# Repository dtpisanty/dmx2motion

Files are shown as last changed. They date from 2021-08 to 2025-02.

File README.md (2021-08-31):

# dmx2motion
An ESP32 based open-hardware project to control varing frequency AC motror drivers through DMX, ArtNet, OSC and MQTT

## Circuit board files
Schematics and PCB files were created using DIP Trace

## Library dependencies
This project uses Lukas Salomons ESP32-DMX Library https://github.com/luksal/ESP32-DMX and ThingPulse's ssd1306 OLED driver https://github.com/ThingPulse/esp8266-oled-ssd1306

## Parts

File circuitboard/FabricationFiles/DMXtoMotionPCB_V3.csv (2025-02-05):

Id | Designator | Footprint | Quantity | Designation | Manufacturer and ref | Link proveedor | Diam
1 | U1 | SIP-4(7)_19.5x6x2.54 | 1 | TEA 1-0505E | Traco Power TEA 1-0505E | https://www.digikey.com.mx/en/products/detail/traco-power/TEA-1-0505E/12093309 | 0.5
2 | J4,J6,J7,J8,J9,J10 | HDR-1x2_J6 | 6 | A0 | Molex 0022232021 | https://www.digikey.com.mx/en/products/detail/molex/0022232021/26667 | 1.02
3 | R13,R5,R4,R6 | R_1206_3216Metric_Pad1.30x1.75mm_HandSolder | 4 | 470Ω | TE CRGCQ1206F470R | https://www.digikey.com.mx/en/products/detail/te-connectivity-passive-product/CRGCQ1206F470R/8576408
4 | C5 | CP_Elec_4x5.3 | 1 | 10uF | Nichicon UWZ1C100MCL1GB | https://www.digikey.com.mx/es/products/detail/nichicon/UWZ1C100MCL1GB/2550873
5 | R1,R2,R3 | R_1206_3216Metric_Pad1.30x1.75mm_HandSolder | 3 | 330Ω | Yageo RC1206JR-07330RL | https://www.digikey.com.mx/en/products/detail/yageo/RC1206JR-07330RL/729279
6 | C1,C7,C8,C9,C3,C2,C6 | C_1206_3216Metric_Pad1.33x1.80mm_HandSolder | 7 | 0.1uF | Walsin Technology Corporation 1206B104K500CT | https://www.digikey.com.mx/en/products/detail/walsin-technology-corporation/1206B104K500CT/9355102
7 | VO1,VO2,VO3 | DIP-8 | 3 | 6N137 | Everlight 6N137 | https://agelectronica.com/detalle?busca=6N%20137 | 0.56
8 | C4 | CP_Elec_4x5.3 | 1 | 4.7 | Nichicon UWP1C4R7MCL1GB | https://www.digikey.com.mx/es/products/detail/nichicon/UWP1C4R7MCL1GB/2550788
9 | J5 | HDR-1x6 | 1 | INTERFACE | Molex 0022232061 | https://www.digikey.com.mx/en/products/detail/molex/0022232061/26675?s=N4IgTCBcDaIAxzEgzGOA2AjCAugXyA | 1.02
10 | R19,R21 | R_1206_3216Metric_Pad1.30x1.75mm_HandSolder | 2 | 2KΩ | Yageo RC1206FR-072KL | https://www.digikey.com.mx/en/products/detail/yageo/RC1206FR-072KL/728612
11 | J1 | BarrelJack_Horizontal | 1 | 12V In | Same sky PJ-002AH | https://www.digikey.com.mx/en/products/detail/same-sky-formerly-cui-devices/PJ-002AH/408446
12 | U2 | DIP-8 | 1 | MAX485CPA | Maxim Integrated MAX485CPA+ | https://www.digikey.com.mx/en/products/detail/analog-devices-inc-maxim-integrated/MAX485CPA/948026 | 0.58
13 | R14,R15,R17,R16 | R_1206_3216Metric_Pad1.30x1.75mm_HandSolder | 4 | 39Ω | Yageo RC1206JR-0739RL | https://www.digikey.com.mx/en/products/detail/yageo/RC1206JR-0739RL/729289
14 | J2,J3 | HDR-1x3 | 2 | XLR3 OUT | Molex 22232031 | https://www.digikey.com.mx/en/products/detail/molex/0022232031/26669 | 1.02
15 | U5 | DIP-8 | 1 | LM358N | STM LM358N | https://agelectronica.com/detalle?busca=LM%20358N
16 | VO4 | DIP-16 | 1 | PC847 | Sharp PC847 | https://agelectronica.com/detalle?busca=PC%20847X
17 | S3,S4 | HDRF-1x3T_2.54_8x3 | 2 | MODE | E-Switch EG1218 | https://www.digikey.com.mx/en/products/detail/e-switch/EG1218/101726 | 1
18 | R8,R7 | R_1206_3216Metric_Pad1.30x1.75mm_HandSolder | 2 | 680Ω | Yageo RC1206JR-07680RL | https://www.digikey.com.mx/en/products/detail/yageo/RC1206JR-07680RL/729328
19 | R20,R10,R9,R18 | R_1206_3216Metric_Pad1.30x1.75mm_HandSolder | 4 | 1KΩ | Yageo RC1206FR-071KL | https://www.digikey.com.mx/en/products/detail/yageo/RC1206FR-071KL/728387
20 | U6 | ESP32-DevKitC | 1 | ESP32-WROOM-32U | N/A | N/A
21 | U4 | TO-220V | 1 | L78S05CV | STM L78S05CV | https://agelectronica.com/detalle?busca=L78S05CV
22 | R12 | R_1206_3216Metric_Pad1.30x1.75mm_HandSolder | 1 | 220Ω | Yageo RC1206JR-07220RL | https://www.digikey.com.mx/en/products/detail/yageo/RC1206JR-07220RL/729251
23 | D1 | LED100 | 1 | LED | Kingbright WP7113GD | https://www.digikey.com.mx/en/products/detail/kingbright/WP7113GD/1747662 | 0.9

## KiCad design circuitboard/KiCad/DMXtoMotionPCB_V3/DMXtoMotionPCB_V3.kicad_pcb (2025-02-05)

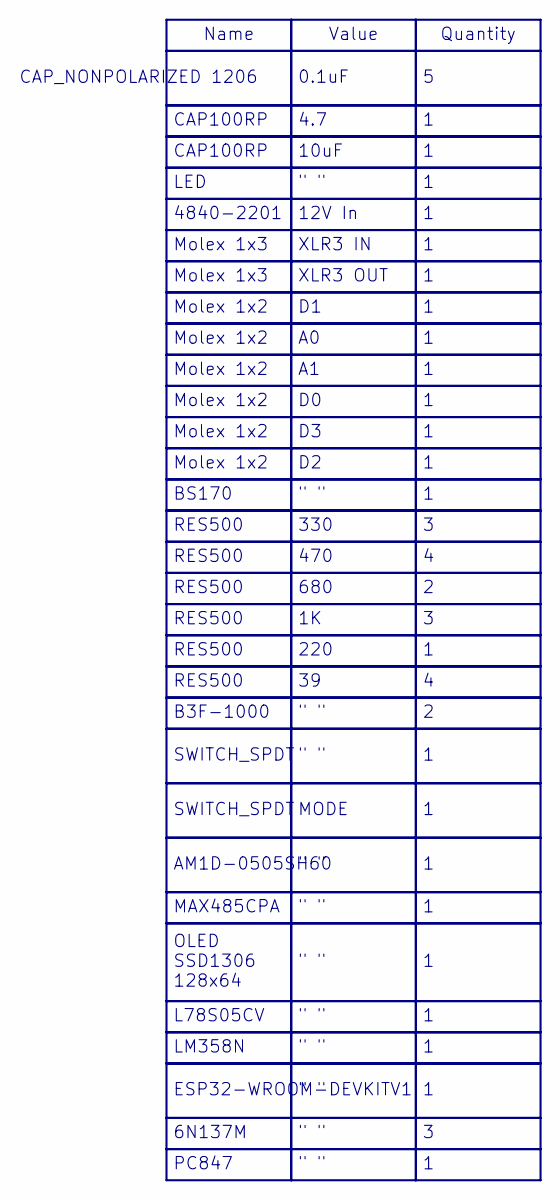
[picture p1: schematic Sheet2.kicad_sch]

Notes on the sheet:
Molex 1x2
" "
CAP100RP
470
L78S05CV
Molex 1x3
6N137M
Name
4840-2201
MAX485CPA
CAP_NONPOLARIZED 1206
RES500
4.7
Value
10uF
B3F-1000
AM1D-0505SH60
LM358N
330
PC847
680
220
0.1uF
LED
SWITCH_SPDT
XLR3 OUT
BS170
12V In
Quantity
MODE
XLR3 IN
OLED SSD1306 128x64
ESP32-WROOM-DEVKITV1

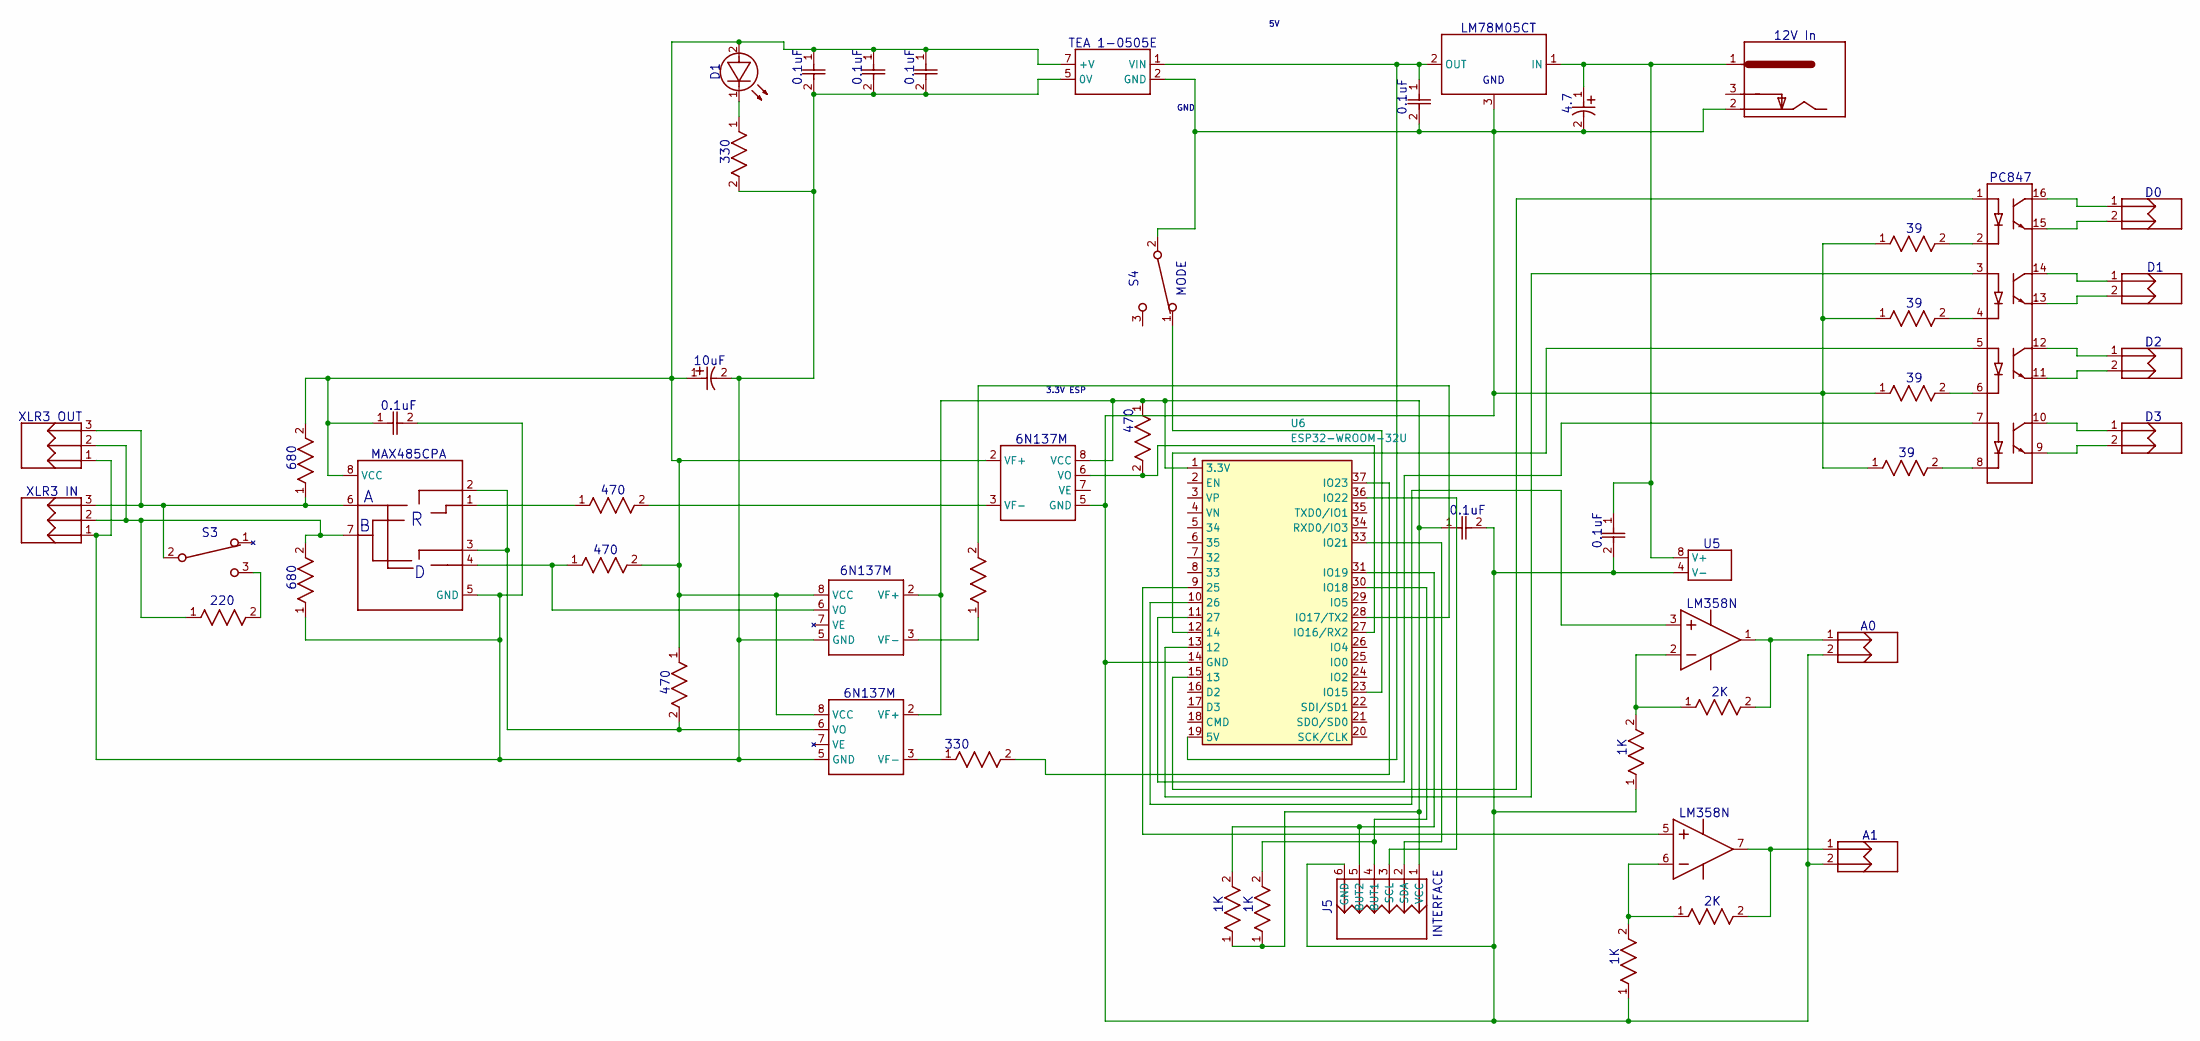
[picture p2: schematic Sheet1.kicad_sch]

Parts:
C1, C2, C3, C6, C7, C8, C9: 0.1uF; C_1206_3216Metric_Pad1.33x1.80mm_HandSolder
C4: 4.7; CP_Elec_4x5.3
C5: 10uF; CP_Elec_4x5.3
D1: LED; LED100
J1: 12V In; BarrelJack_Horizontal
J2: XLR3 IN; HDR-1X3
J3: XLR3 OUT; HDR-1X3
J4: D1; HDR-1X2
J5: INTERFACE; HDR-1X6
J6: A0; HDR-1X2
J7: A1; HDR-1X2
J8: D0; HDR-1X2
J9: D3; HDR-1X2
J10: D2; HDR-1X2
R1, R2, R3: 330; R_1206_3216Metric_Pad1.30x1.75mm_HandSolder
R4, R5, R6, R13: 470; R_1206_3216Metric_Pad1.30x1.75mm_HandSolder
R7, R8: 680; R_1206_3216Metric_Pad1.30x1.75mm_HandSolder
R9, R10, R18, R20: 1K; R_1206_3216Metric_Pad1.30x1.75mm_HandSolder
R12: 220; R_1206_3216Metric_Pad1.30x1.75mm_HandSolder
R14, R15, R16, R17: 39; R_1206_3216Metric_Pad1.30x1.75mm_HandSolder
R19, R21: 2K; R_1206_3216Metric_Pad1.30x1.75mm_HandSolder
S3: SWITCH_SPDT; HDRF-1X3T_2.54_8X3
S4: MODE; HDRF-1X3T_2.54_8X3
U1: AM1D-0505SH60; SIP-4(7)_19.5X6X2.54
U2: MAX485CPA; DIP-8
U4: LM78M05CT; TO-220V
U5: LM358N; DIP-8
U6: ESP32-WROOM-32U; ESP32-DevKitC
VO1, VO2, VO3: 6N137M; DIP-8
VO4: PC847; DIP-16

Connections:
3.3V_ESP: C7.1, J5.1 (VCC), R9.1 (A), R10.1 (A), R13.1 (A), U6.1 (3.3V), VO1.8 (VCC), VO2.2 (VF+), VO3.2 (VF+)
5V: C9.1, U1.1 (VIN), U4.2 (OUT), U6.19 (5V)
12V: C4.1 (PLUS), C6.1, J1.1, U4.1 (IN), U5.8 (V+)
But1: J5.4 (BUT1), R10.2 (B), U6.30 (IO18)
But2: J5.5 (BUT2), R9.2 (B), U6.31 (IO19)
GND: C4.2 (MINUS), C6.2, C7.2, C9.2, J1.2, J5.6 (GND), J6.2, J7.2, R14.1 (A), R15.1 (A), R16.1 (A), R17.1 (A), R18.1 (A), R20.1 (A), S4.2 (C1), U1.2 (GND), U4.3 (GND), U5.4 (V-), U6.14 (GND), U6.32 (GND), U6.38 (GND), VO1.5 (GND)
ISO-5V: C1.1, C2.1, C3.1, C5.1 (PLUS), C8.1, D1.2 (A), R5.2 (B), R6.1 (A), R7.2 (B), U1.7 (+V), U2.8 (VCC), VO1.2 (VF+), VO2.8 (VCC), VO3.8 (VCC)
ISO-GND: C1.2, C2.2, C3.2, C5.2 (MINUS), C8.2, J2.1, J3.1, R1.2 (B), R8.1 (A), U1.5 (0V), U2.5 (GND), VO2.5 (GND), VO3.5 (GND)
Net_0: R17.2 (B), VO4.2 (Cathode@1)
Net_1: U6.12 (14), VO4.5 (Anode@3)
Net_2: U6.11 (27), VO4.7 (Anode@4)
Net_4: D1.1 (K), R1.1 (A)
Net_6: U6.15 (13), VO4.1 (Anode@1)
Net_7: U6.13 (12), VO4.3 (Anode@2)
Net_8: U5.5 (IN+), U6.9 (25)
Net_9: R2.1 (A), VO2.3 (VF-)
Net_10: R3.2 (B), U6.37 (IO23)
Net_11: R3.1 (A), VO3.3 (VF-)
Net_12: R4.2 (B), VO1.3 (VF-)
Net_13: R4.1 (A), U2.1 (RO)
Net_14: R6.2 (B), U2.2 (~RE), U2.3 (DE), VO3.6 (VO)
Net_15: R5.1 (A), U2.4 (DI), VO2.6 (VO)
Net_16: J2.2, J3.2, R8.2 (B), R12.1 (A), U2.7 (B)
Net_17: J2.3, J3.3, R7.1 (A), S3.2 (C1), U2.6 (A)
Net_18: J7.1, R19.2 (B), U5.7 (OUT)
Net_21: R18.2 (B), R19.1 (A), U5.6 (IN-)
Net_22: S4.1 (C2), U6.23 (IO15)
Net_24: U5.3 (IN+), U6.10 (26)
Net_32: J5.2 (SDA), U6.33 (IO21)
Net_33: J5.3 (SCL), U6.36 (IO22)
Net_34: R12.2 (B), S3.3 (C3)
Net_35: R14.2 (B), VO4.4 (Cathode@2)
Net_36: R15.2 (B), VO4.6 (Cathode@3)
Net_37: R16.2 (B), VO4.8 (Cathode@4)
Net_38: J8.2, VO4.15 (Emitter@1)
Net_39: J8.1, VO4.16 (Collector@1)
Net_40: J4.1, VO4.14 (Collector@2)
Net_41: J4.2, VO4.13 (Emitter@2)
Net_42: J10.1, VO4.12 (Collector@3)
Net_43: J10.2, VO4.11 (Emitter@3)
Net_44: J9.1, VO4.10 (Collector@4)
Net_45: J9.2, VO4.9 (Emitter@4)
Net_46: J6.1, R21.2 (B), U5.1 (OUT)
Net_47: R20.2 (B), R21.1 (A), U5.2 (IN-)
RX: R13.2 (B), U6.27 (IO16/RX2), VO1.6 (VO)
TX: R2.2 (B), U6.28 (IO17/TX2)

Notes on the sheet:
PC847
330
6N137M
GND
0.1uF
10uF
470
XLR3 IN
XLR3 OUT
LM358N
MODE
TEA 1-0505E
680
INTERFACE
3.3V ESP
12V In
220
LM78M05CT
MAX485CPA
4.7

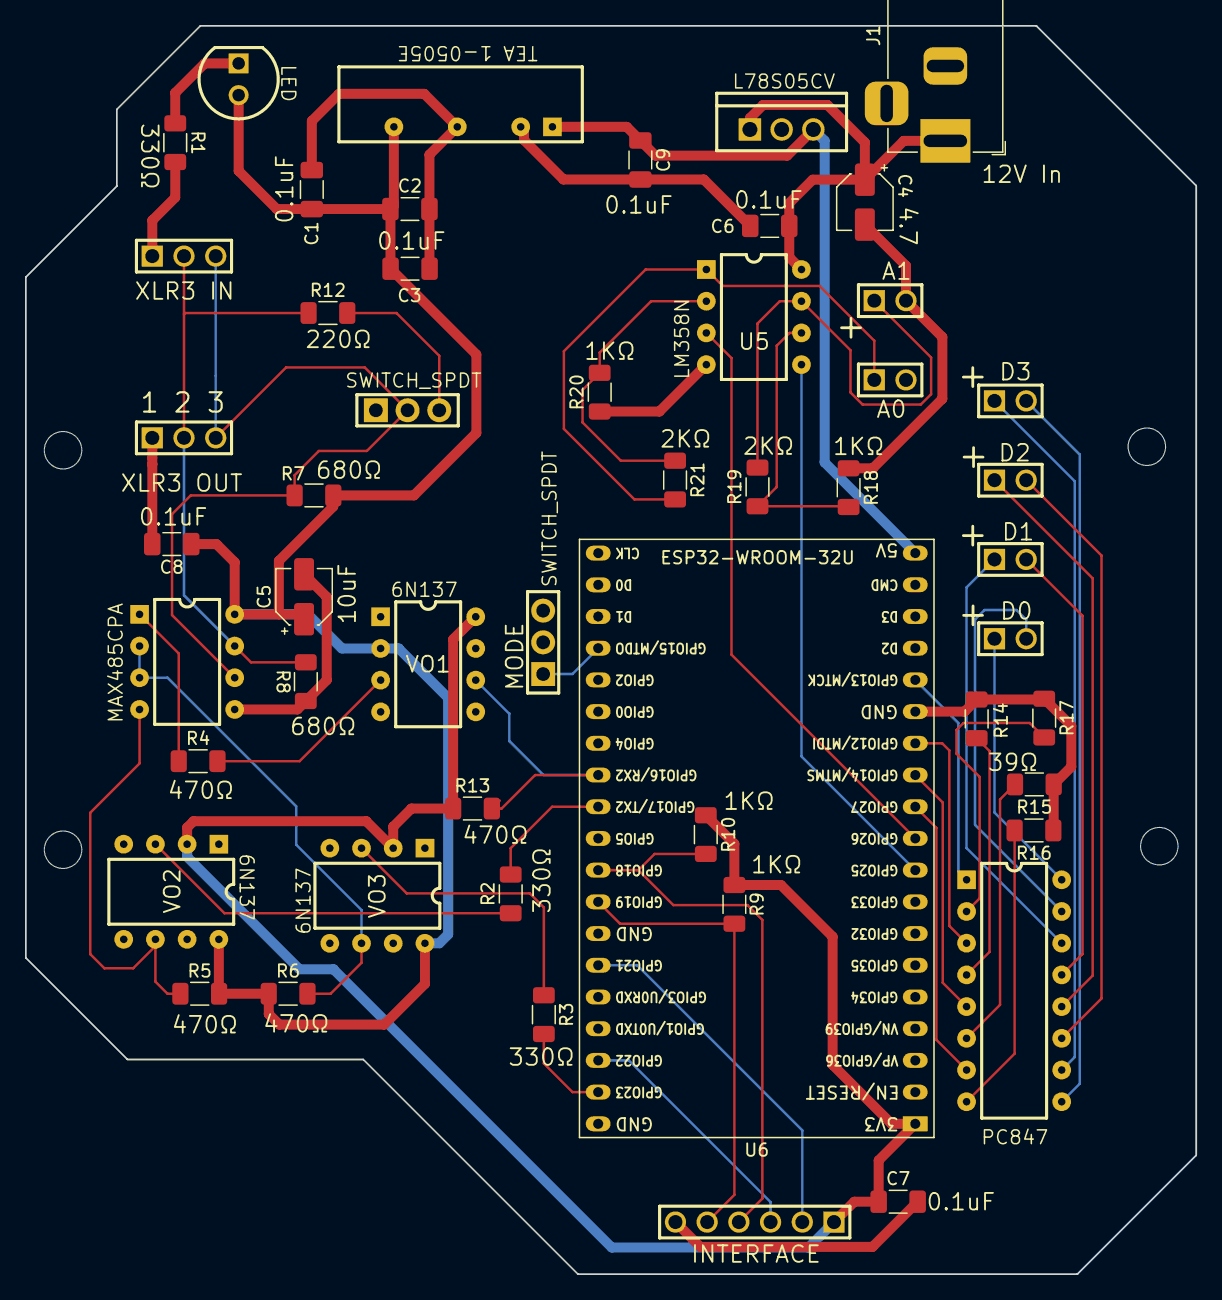
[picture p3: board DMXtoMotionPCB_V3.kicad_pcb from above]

Board: 2 copper layers, 93.8 x 100.0 mm, 55 parts (0 on the bottom side), 46 nets.

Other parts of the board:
@HOLE0, @HOLE1, @HOLE2, @HOLE3: (no value)

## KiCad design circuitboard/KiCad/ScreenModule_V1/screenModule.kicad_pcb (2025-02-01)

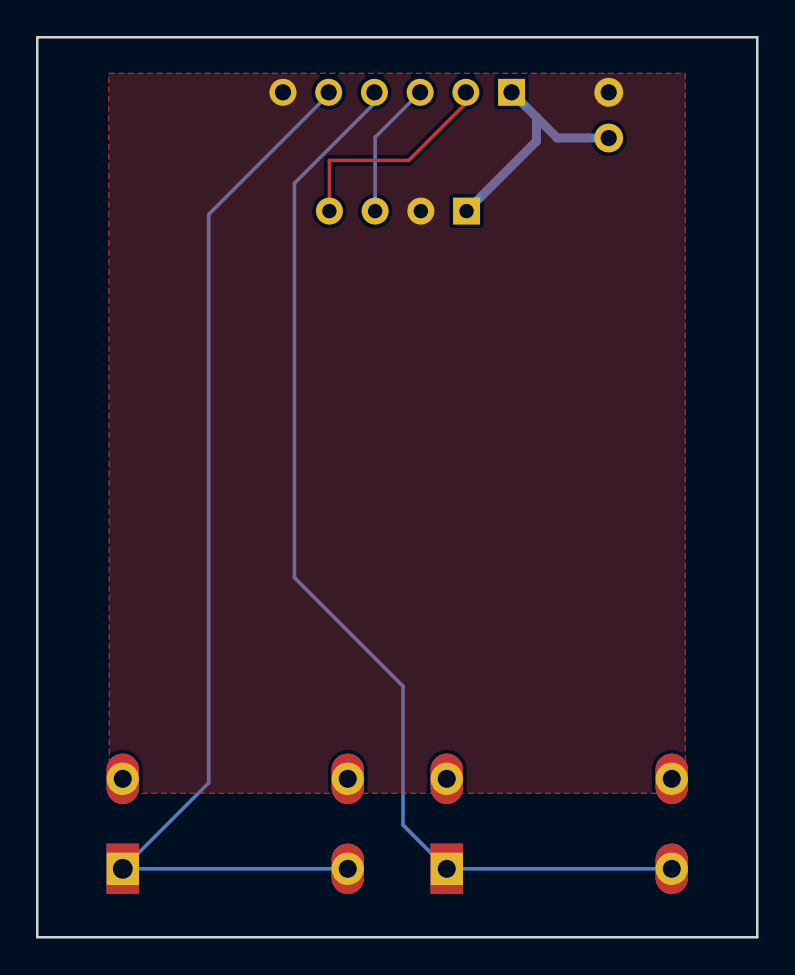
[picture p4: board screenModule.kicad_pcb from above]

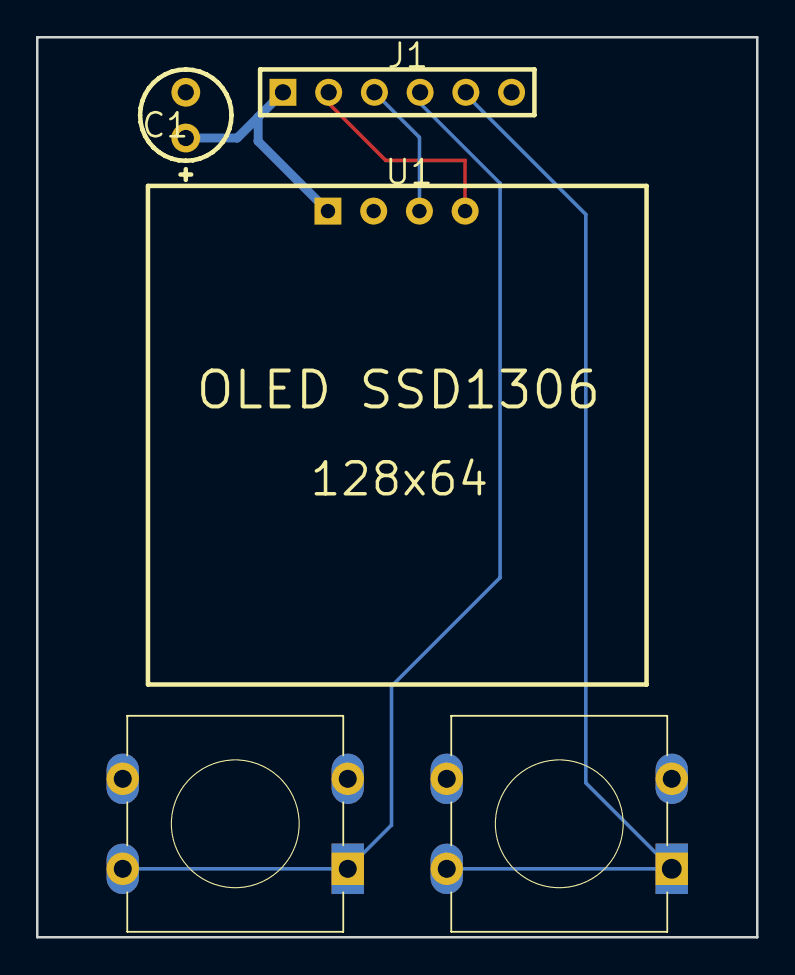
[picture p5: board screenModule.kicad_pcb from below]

Board: 2 copper layers, 40.0 x 50.0 mm, 11 parts (11 on the bottom side), 6 nets.

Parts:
C1: 4.7uF; CAPPR-2.54_5.08
J1: HDR-1X6; HDR-1x6
PAD1: PAD; PAD_PAD1
PAD2, PAD3, PAD4, PAD6, PAD7, PAD8: PAD; PAD_PAD2
PAD5: PAD
U1: OLED SSD1306 128X64; OLED_SSD1306

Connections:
Net_0: C1.2, J1.6, U1.2
Net_1: C1.1, J1.1, U1.1
Net_2: J1.2, U1.4
Net_3: J1.3, U1.3
Net_5: J1.5, PAD1.1, PAD2.2
Net_6: J1.4, PAD5.1, PAD6.2

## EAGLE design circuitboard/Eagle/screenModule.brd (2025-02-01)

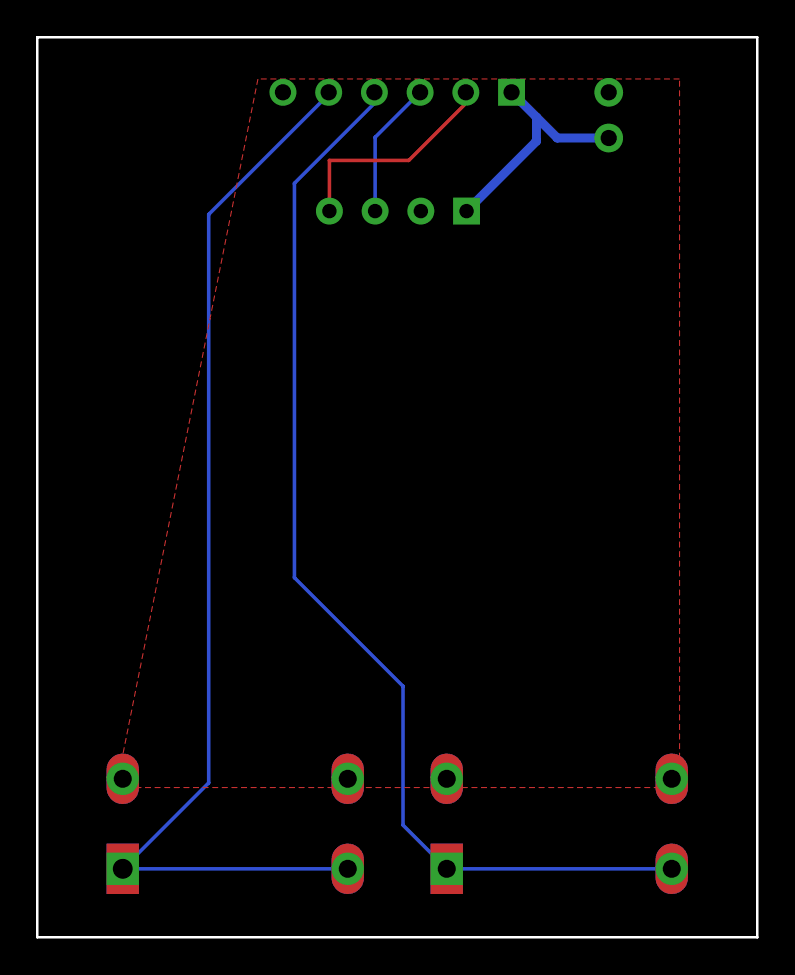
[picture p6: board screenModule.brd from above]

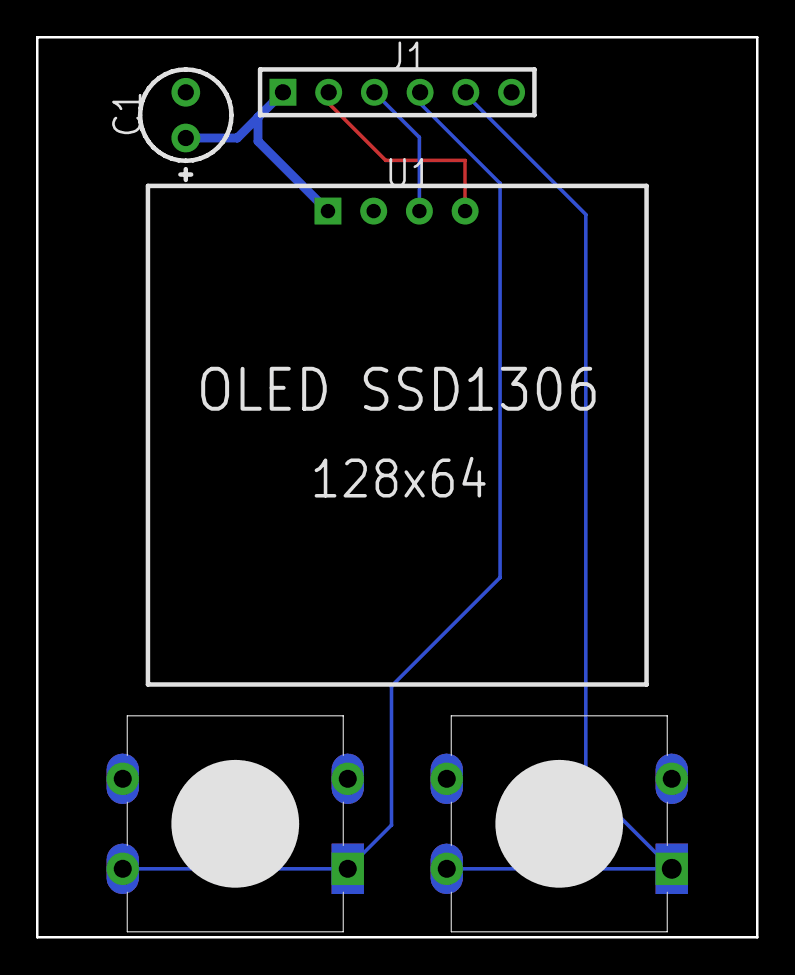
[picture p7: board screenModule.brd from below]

Board: 2 copper layers, 40.0 x 50.0 mm, 11 parts (11 on the bottom side), 6 nets.

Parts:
C1: 4.7uF; CAPPR-2.54/5.08
J1: HDR-1X6; HDR-1x6
PAD1: PAD; PAD_PAD1
PAD2, PAD3, PAD4, PAD6, PAD7, PAD8: PAD; PAD_PAD2
PAD5: PAD
U1: OLED SSD1306 128X64; OLED_SSD1306

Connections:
Net_0: C1.2, J1.6, PAD3.3, PAD4.4, PAD7.3, PAD8.4, U1.2
Net_1: C1.1, J1.1, U1.1
Net_2: J1.2, U1.4
Net_3: J1.3, U1.3
Net_5: J1.5, PAD1.1, PAD2.2
Net_6: J1.4, PAD5.1, PAD6.2

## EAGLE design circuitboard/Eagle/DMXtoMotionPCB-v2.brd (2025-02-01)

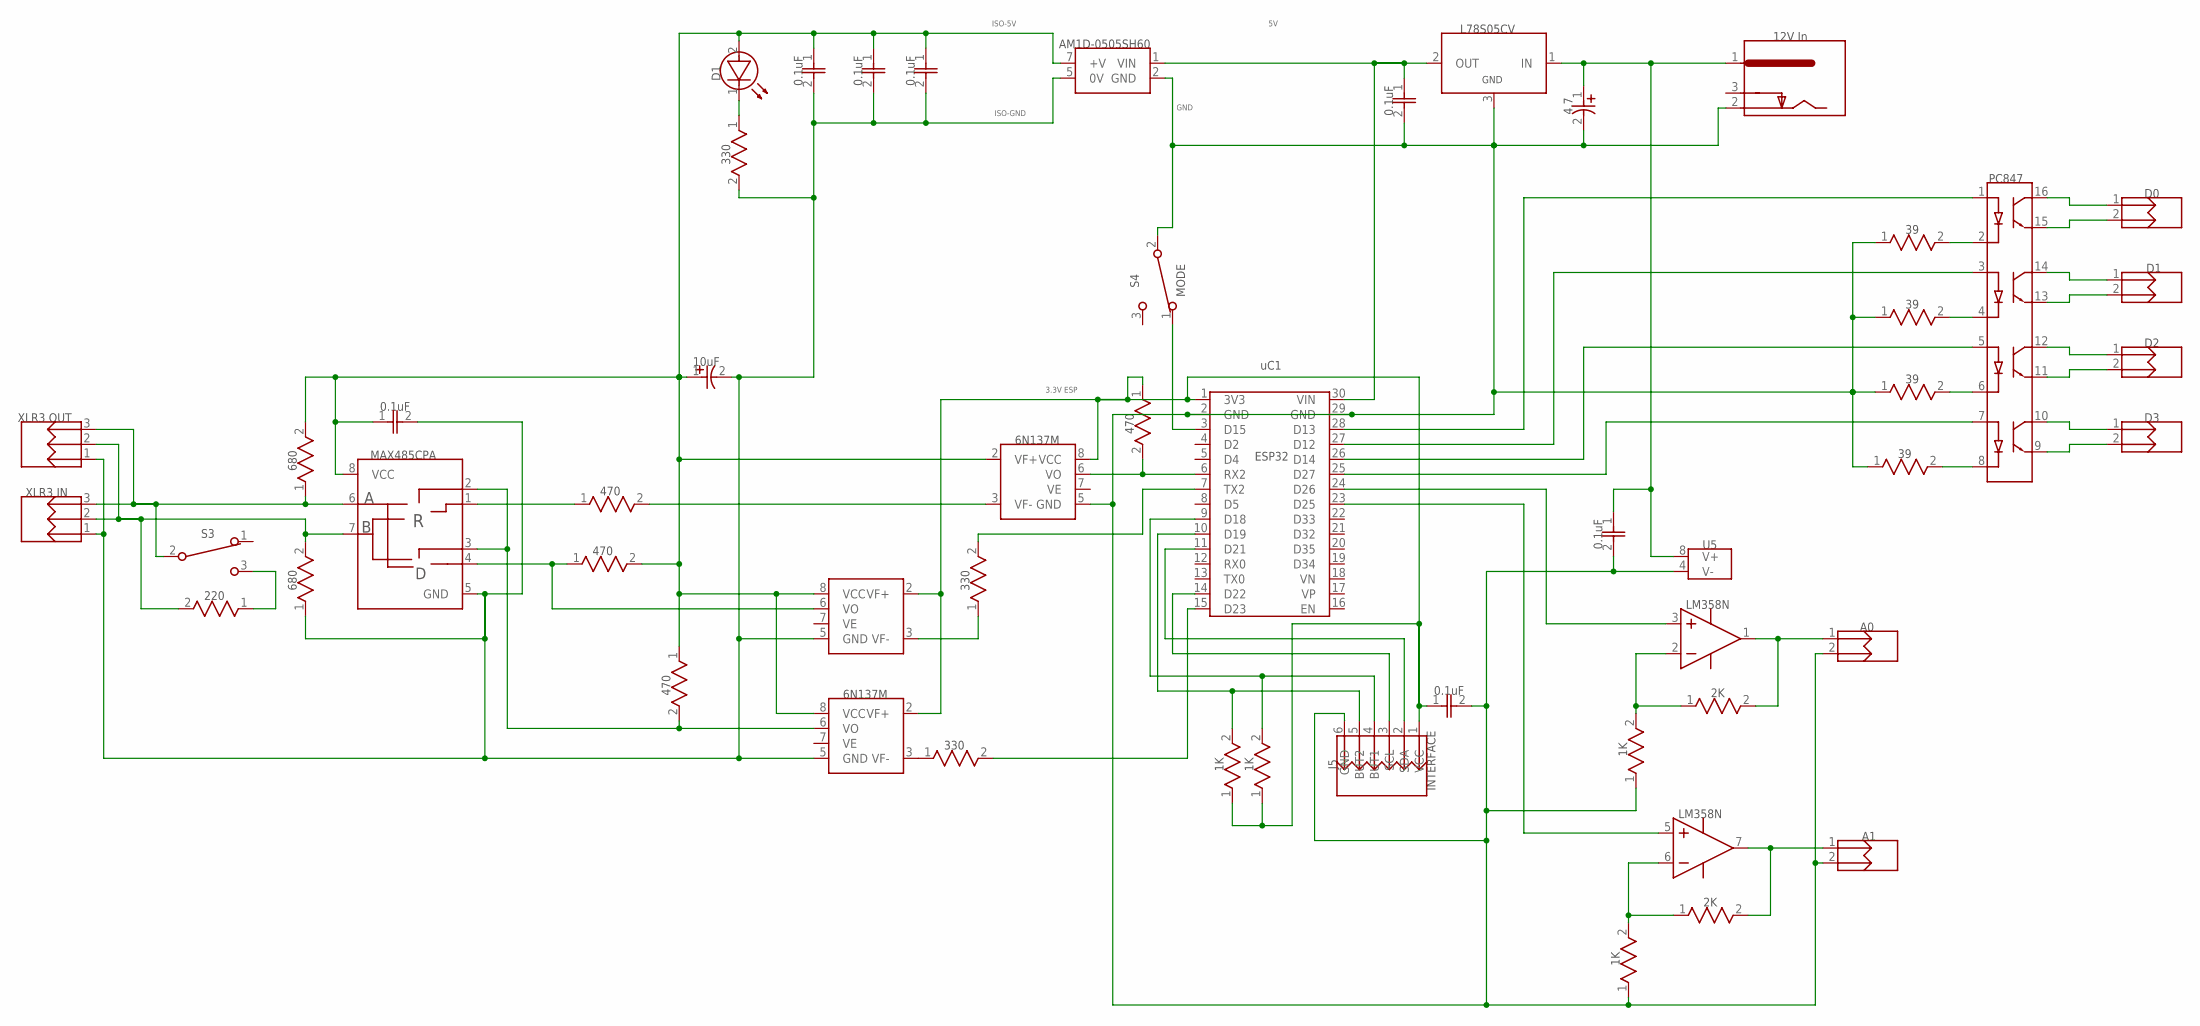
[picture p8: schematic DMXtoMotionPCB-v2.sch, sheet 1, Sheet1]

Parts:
C1, C2, C3, C6, C7, C8, C9: 0.1uF; CAP-5.08/9.15X3
C4: 4.7; CAPPR-2.54/5.08
C5: 10uF; CAPPR-2.54/5.08
D1: LED; LED100
J1: 12V In; 4840-2211
J2: XLR3 IN; HDR-1X3
J3: XLR3 OUT; HDR-1X3
J4: D1; HDR-1X2
J5: INTERFACE; HDR-1X6
J6: A0; HDR-1X2
J7: A1; HDR-1X2
J8: D0; HDR-1X2
J9: D3; HDR-1X2
J10: D2; HDR-1X2
R1, R2, R3: 330; RES-12.7/7.6X2.5
R4, R5, R6, R13: 470; RES-12.7/7.6X2.5
R7, R8: 680; RES-12.7/7.6X2.5
R9, R10, R18, R20: 1K; RES-12.7/7.6X2.5
R12: 220; RES-12.7/7.6X2.5
R14, R15, R16, R17: 39; RES-12.7/7.6X2.5
R19, R21: 2K; RES-12.7/7.6X2.5
S3: SWITCH_SPDT; HDRF-1X3T/2.54/8X3
S4: MODE; HDRF-1X3T/2.54/8X3
U1: AM1D-0505SH60; SIP-4(7)/19.5X6X2.54
U2: MAX485CPA; DIP-8
U4: L78S05CV; TO-220V
U5: LM358N; DIP-8
VO1: 6N137M; DIP-8
VO2, VO3: 6N137M_10; DIP-8
VO4: PC847; DIP-16
uC1: ESP32-WROOM-DEVKITV1; ESP32-DEVKITV1

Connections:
3.3V_ESP: C7.1, J5.1 (VCC), R9.1 (A), R10.1 (A), R13.1 (A), VO1.8 (VCC), VO2.2 (VF+), VO3.2 (VF+), uC1.1 (3V3)
5V: C9.1, U1.1 (VIN), U4.2 (OUT), uC1.30 (VIN)
12V: C4.1 (PLUS), C6.1, J1.1, U4.1 (IN), U5.8 (V+)
But1: J5.4 (BUT1), R10.2 (B), uC1.9 (D18)
But2: J5.5 (BUT2), R9.2 (B), uC1.10 (D19)
GND: C4.2 (MINUS), C6.2, C7.2, C9.2, J1.2, J5.6 (GND), J6.2, J7.2, R14.1 (A), R15.1 (A), R16.1 (A), R17.1 (A), R18.1 (A), R20.1 (A), S4.2 (C1), U1.2 (GND), U4.3 (GND), U5.4 (V-), VO1.5 (GND), uC1.2 (GND), uC1.29 (GND)
ISO-5V: C1.1, C2.1, C3.1, C5.1 (PLUS), C8.1, D1.2 (A), R5.2 (B), R6.1 (A), R7.2 (B), U1.7 (+V), U2.8 (VCC), VO1.2 (VF+), VO2.8 (VCC), VO3.8 (VCC)
ISO-GND: C1.2, C2.2, C3.2, C5.2 (MINUS), C8.2, J2.1, J3.1, R1.2 (B), R8.1 (A), U1.5 (0V), U2.5 (GND), VO2.5 (GND), VO3.5 (GND)
Net_0: R17.2 (B), VO4.2 (Cathode)
Net_1: VO4.5 (Anode), uC1.26 (D14)
Net_2: VO4.7 (Anode), uC1.25 (D27)
Net_4: D1.1 (K), R1.1 (A)
Net_6: VO4.1 (Anode), uC1.28 (D13)
Net_7: VO4.3 (Anode), uC1.27 (D12)
Net_8: U5.5 (IN+), uC1.23 (D25)
Net_9: R2.1 (A), VO2.3 (VF-)
Net_10: R3.2 (B), uC1.15 (D23)
Net_11: R3.1 (A), VO3.3 (VF-)
Net_12: R4.2 (B), VO1.3 (VF-)
Net_13: R4.1 (A), U2.1 (RO)
Net_14: R6.2 (B), U2.2 (!RE), U2.3 (DE), VO3.6 (VO)
Net_15: R5.1 (A), U2.4 (DI), VO2.6 (VO)
Net_16: J2.2, J3.2, R8.2 (B), R12.2 (B), U2.7 (B)
Net_17: J2.3, J3.3, R7.1 (A), S3.2 (C1), U2.6 (A)
Net_18: J7.1, R19.2 (B), U5.7 (OUT)
Net_21: R18.2 (B), R19.1 (A), U5.6 (IN-)
Net_22: S4.1 (C2), uC1.3 (D15)
Net_24: U5.3 (IN+), uC1.24 (D26)
Net_32: J5.2 (SDA), uC1.11 (D21)
Net_33: J5.3 (SCL), uC1.14 (D22)
Net_34: R12.1 (A), S3.3 (C3)
Net_35: R14.2 (B), VO4.4 (Cathode)
Net_36: R15.2 (B), VO4.6 (Cathode)
Net_37: R16.2 (B), VO4.8 (Cathode)
Net_38: J8.2, VO4.15 (Emitter)
Net_39: J8.1, VO4.16 (Collector)
Net_40: J4.1, VO4.14 (Collector)
Net_41: J4.2, VO4.13 (Emitter)
Net_42: J10.1, VO4.12 (Collector)
Net_43: J10.2, VO4.11 (Emitter)
Net_44: J9.1, VO4.10 (Collector)
Net_45: J9.2, VO4.9 (Emitter)
Net_46: J6.1, R21.2 (B), U5.1 (OUT)
Net_47: R20.2 (B), R21.1 (A), U5.2 (IN-)
RX: R13.2 (B), VO1.6 (VO), uC1.6 (RX2)
TX: R2.2 (B), uC1.7 (TX2)

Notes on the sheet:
0.1uF
4.7
10uF
12V In
XLR3 IN
XLR3 OUT
INTERFACE
330
470
680
220
MODE
AM1D-0505SH60
MAX485CPA
GND
L78S05CV
LM358N
ESP32
uC1
6N137M
PC847
3.3V ESP
ISO-5V
ISO-GND

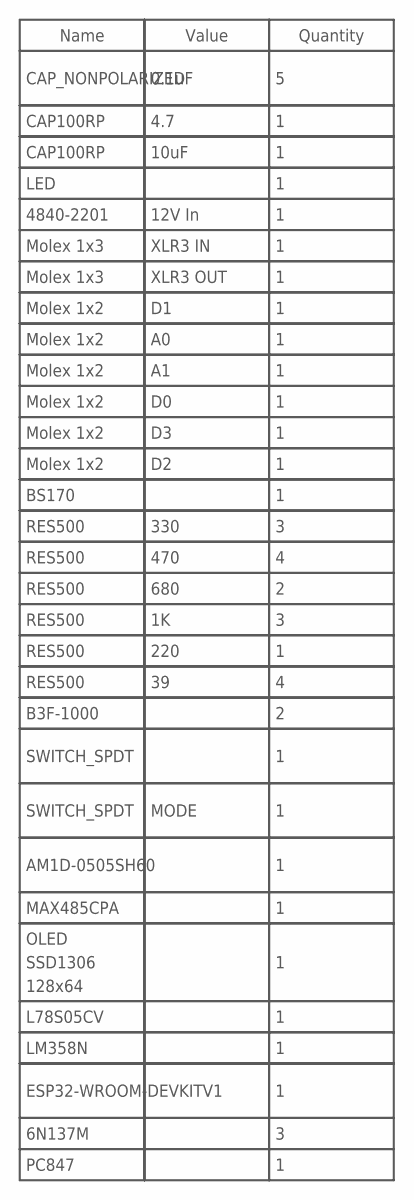
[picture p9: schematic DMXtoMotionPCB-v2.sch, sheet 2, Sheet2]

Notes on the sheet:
Name
CAP_NONPOLARIZED
CAP100RP
LED
4840-2201
Molex 1x3
Molex 1x2
BS170
RES500
B3F-1000
SWITCH_SPDT
AM1D-0505SH60
MAX485CPA
OLED SSD1306 128x64
L78S05CV
LM358N
ESP32-WROOM-DEVKITV1
6N137M
PC847
Value
0.1uF
4.7
10uF
12V In
XLR3 IN
XLR3 OUT
330
470
680
220
MODE
Quantity

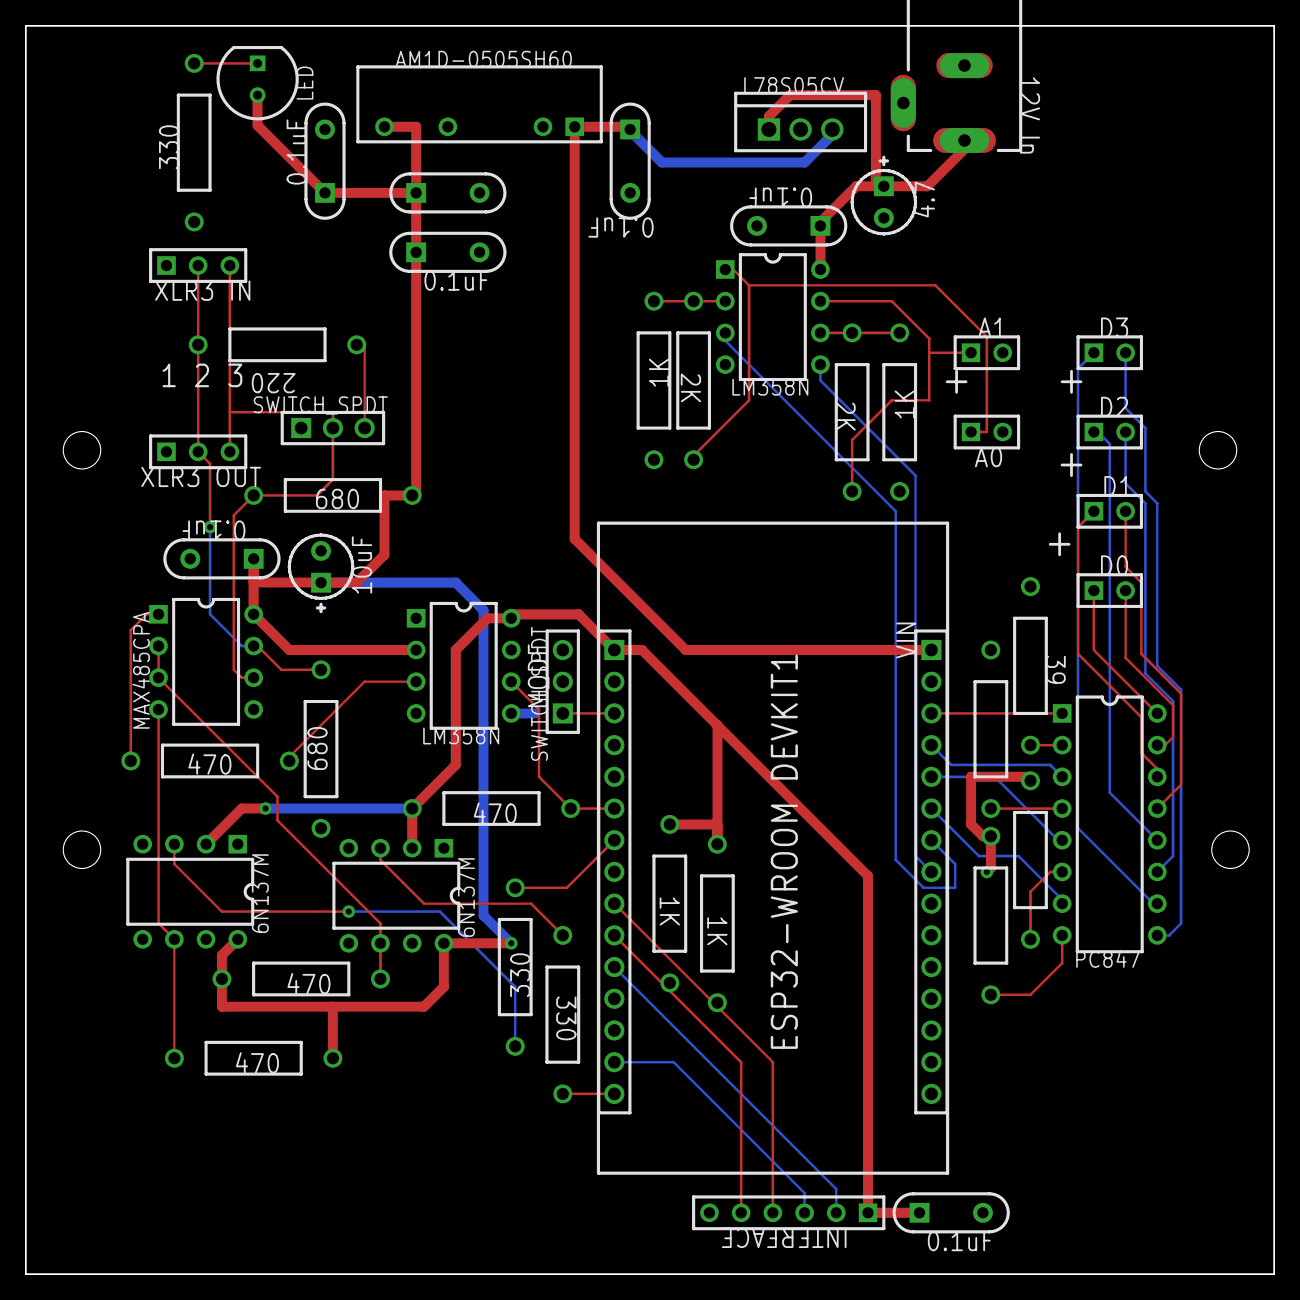
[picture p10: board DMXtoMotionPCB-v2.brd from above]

Board: 2 copper layers, 100.0 x 100.0 mm, 51 parts (0 on the bottom side), 46 nets.

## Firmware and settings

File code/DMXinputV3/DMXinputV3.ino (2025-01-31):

#include <dmx.h>
#include "SSD1306Wire.h"
#include <EEPROM.h>
#include "WiFi.h"
#include <PubSubClient.h>

#define debug true

//EEPROM
#define EEPROM_SIZE 1
bool saveChannel = false;


//////////////////////////////////////////////////////
//         PINES SALIDA (13,12,14,27,26,25)         //
//////////////////////////////////////////////////////
#define enablePin 23
#define dOut0 13
#define dOut1 12
#define dOut2 14
#define dOut3 27
#define DAC0 26
#define DAC1 25

//////////////////////////////////////////////////////
//                BOTONES                           //
//////////////////////////////////////////////////////
#define chUp 18
#define chDown 19
bool showChannel = false;
long chShowTimer = 0;

//MODO
#define modeSwitch 15
int modo; // 0/LOW=DMX  1/HIGH=MQTT

//////////////////////////////////////////////////////
//                PANTALLA                          //
//////////////////////////////////////////////////////
SSD1306Wire display(0x3c, SDA, SCL);
long lastShow = 0;
bool render = true;

//////////////////////////////////////////////////////
//                VARIABLES                         //
//////////////////////////////////////////////////////
bool eStop = false;
int readcycle = 0;
int valD0 = 0;
int valD1 = 0;
int valA0 = 0;
int valD2 = 0;
int valD3 = 0;
int valA1 = 0;

int startDMXChannel = 0;
long lastAdd = 0;

//////////////////////////////////////////////////////
//                 INTERRUPTS                       //
//////////////////////////////////////////////////////
void IRAM_ATTR addChannel() {
  saveChannel = true;
  //Debounce
  if (millis() - lastAdd < 150) {
    return;
  }
  lastAdd = millis();
  startDMXChannel++;
  if (startDMXChannel > 510) {
    startDMXChannel = 510;
  }
  showChannel = true;
  chShowTimer = millis();
  if (EEPROM.read(0) == startDMXChannel) {
    saveChannel = false;
  }
#if debug
  Serial.println(startDMXChannel);
#endif
}

long lastSubtract = 0;
void IRAM_ATTR subtractChannel() {
  saveChannel = true;
  if (millis() - lastSubtract < 150) {
    return;
  }
  lastSubtract = millis();
  startDMXChannel--;
  if (startDMXChannel < 1) {
    startDMXChannel = 1;
  }
  showChannel = true;
  chShowTimer = millis();
  if (EEPROM.read(0) == startDMXChannel) {
    saveChannel = false;
  }

#if debug
  Serial.println(startDMXChannel);
#endif
}
void IRAM_ATTR reboot() {
  ESP.restart();
}
//////////////////////////////////////////////////////
//                 WIFI                             //
//////////////////////////////////////////////////////
//const char* ssid = "Totalplay-7F9A";
//const char* password = "7F9AE96AmFef7T6b";
const char* ssid = "IZZI-4B88";
const char* password = "usy7qijh";
void setup_wifi() {
  delay(5);
#if debug
  Serial.println();
  Serial.print("Conectando a ");
  Serial.println(ssid);
#endif
  WiFi.mode(WIFI_STA);
  WiFi.begin(ssid, password);

  while (WiFi.status() != WL_CONNECTED) {
    display.clear();
    display.setTextAlignment(TEXT_ALIGN_CENTER);
    display.setFont(ArialMT_Plain_16);
    display.drawString(64, 10, "CONECTANDO");
    display.drawString(64, 30, ssid);
    display.display();
    delay(500);
#if debug
    Serial.print(".");
#endif
  }
#if debug
  Serial.println("");
  Serial.println("WiFi conectado");
  Serial.println("IP local: ");
  Serial.println(WiFi.localIP());
#endif
}

//////////////////////////////////////////////////////
//                 MQTT                             //
//////////////////////////////////////////////////////
const char* mqtt_server = "tarimas.local";
const int port = 1883;
WiFiClient espClient;
PubSubClient cliente(espClient);
const int statLed = 2;

void reconnect() {
  // Loop until we're reconnected
  while (!cliente.connected()) {
#if debug
    Serial.print("Attempting MQTT connection...");
#endif
    // Create a random client ID
    String clientId = "totaShow-Tarima1";
    // Attempt to connect
    //String id, String willTopic, uint8_t willQos, bool willRetain, String willMessage
    if (cliente.connect(clientId.c_str(), "totalShow", "showtotal2024","tarima1/estado", 2, true, "0")) {
#if debug
      Serial.println("MQTT conectado");
#endif
      // Once connected, publish an announcement...
      cliente.publish("tarima1/estado", "1");
    } else {
#if debug
      Serial.print("Error, codigo=");
      Serial.print(cliente.state());
      Serial.println("intentando en 3 seg");
#endif
      // Wait 5 seconds before retrying
      delay(3000);
    }
  }
  char chTopic[9];
  sprintf(chTopic, "canal/%d", startDMXChannel);
  cliente.subscribe(chTopic);
  sprintf(chTopic, "canal/%d", startDMXChannel + 1);
  cliente.subscribe(chTopic);
  sprintf(chTopic, "canal/%d", startDMXChannel + 2);
  cliente.subscribe(chTopic);
  sprintf(chTopic, "canal/%d", startDMXChannel + 3);
  cliente.subscribe(chTopic);
  sprintf(chTopic, "canal/%d", startDMXChannel + 4);
  cliente.subscribe(chTopic);
  sprintf(chTopic, "canal/%d", startDMXChannel + 5);
  cliente.subscribe(chTopic);
  digitalWrite(statLed, HIGH);
#if debug
  Serial.println("");
  Serial.println("Subscrito a canal/" + String(startDMXChannel));
  Serial.println("Subscrito a canal/" + String(startDMXChannel + 1));
  Serial.println("Subscrito a canal/" + String(startDMXChannel + 2));
  Serial.println("Subscrito a canal/" + String(startDMXChannel + 3));
  Serial.println("Subscrito a canal/" + String(startDMXChannel + 4));
  Serial.println("Subscrito a canal/" + String(startDMXChannel + 5));
#endif

}
void callback(char* topic, byte * payload, unsigned int length) {
#if debug
  Serial.print("Mensaje llego a: ");
  Serial.println(topic);
  Serial.print("Len: ");
  Serial.println(length);
#endif
  String strTopic = String(topic);
  char entrada[length];
  for (int i = 0; i < length; i++) {
    entrada[i] = payload[i];
  }
  //Serial.println(entrada);
  int entradaInt;
  entradaInt = String(entrada).substring(0, length).toInt(); //Convertir entrada de char[] a int
#if debug
  Serial.println(entradaInt);
#endif

  if (strTopic.indexOf(String(startDMXChannel)) > 0) {
    valD0 = entradaInt;
#if debug
    Serial.print("D0=");
    Serial.println(entradaInt);
#endif
  }
  else if (strTopic.indexOf(String(startDMXChannel + 1)) > 0) {
    valD1 = entradaInt;
    Serial.print("D1=");
    Serial.println(entradaInt);
  }
  else if (strTopic.indexOf(String(startDMXChannel + 2)) > 0) {
    valA0 = entradaInt;
    Serial.print("A0=");
    Serial.println(entradaInt);
  }
  else if (strTopic.indexOf(String(startDMXChannel + 3)) > 0) {
    valD2 = entradaInt;
    Serial.print("D2=");
    Serial.println(entradaInt);
  }
  else if (strTopic.indexOf(String(startDMXChannel + 4)) > 0) {
    valD3 = entradaInt;
    Serial.print("D3=");
    Serial.println(entradaInt);
  }
  else if (strTopic.indexOf(String(startDMXChannel + 5)) > 0) {
    valA1 = entradaInt;
    Serial.print("A1=");
    Serial.println(entradaInt);
  }
}

//////////////////////////////////////////////////////
//                 SETUP                            //
//////////////////////////////////////////////////////
void setup() {
#if debug
  Serial.begin(115200);
#endif

  //ENTRADAS
  pinMode(chUp, INPUT_PULLUP);
  pinMode(chDown, INPUT_PULLUP);
  pinMode(modeSwitch, INPUT_PULLUP);
  attachInterrupt(chUp, addChannel, RISING);
  attachInterrupt(chDown, subtractChannel, RISING);
  attachInterrupt(modeSwitch, reboot, CHANGE);
  //SALIDAS
  pinMode(enablePin, OUTPUT);
  pinMode(dOut0, OUTPUT);
  pinMode(dOut1, OUTPUT);
  pinMode(dOut2, OUTPUT);
  pinMode(dOut3, OUTPUT);
  pinMode(DAC0, OUTPUT);
  pinMode(DAC1, OUTPUT);
  digitalWrite(enablePin, LOW);

  //PANTALLA
  display.init();
  display.flipScreenVertically();
  display.setBrightness(255);
  display.setContrast(255);
  display.setFont(ArialMT_Plain_16);
  //MODO
  modo = digitalRead(modeSwitch);
  display.clear();
  display.setTextAlignment(TEXT_ALIGN_CENTER);
  display.setFont(ArialMT_Plain_16);
  if (modo == LOW) {
    display.drawString(64, 43, "DMX");
  }
  else {
    display.drawString(64, 43, "MQTT");
  }
  display.display();
  delay(1000);
#if debug
  Serial.print("MODO: ");
  Serial.println(modo);
#endif

  //MEMORIA
  EEPROM.begin(EEPROM_SIZE);
  startDMXChannel = EEPROM.read(0);
  //DMX
  if (modo == LOW) {
    DMX::Initialize(input);
  }

  //MQTT
  else {
    pinMode(statLed, OUTPUT);
    setup_wifi();
    cliente.setServer(mqtt_server, port);
    cliente.setCallback(callback);
  }
}

//////////////////////////////////////////////////////
//                 LOOP                             //
//////////////////////////////////////////////////////
void loop()
{
  /////////////////////////
  //        DMX         //
  ////////////////////////
  if (modo == LOW) {
    if (millis() - readcycle > 25)
    {
      readcycle = millis();
#if debug
      Serial.print(readcycle);
#endif

      if (DMX::IsHealthy())
      {
        display.clear();
        display.setTextAlignment(TEXT_ALIGN_LEFT);
        display.setFont(ArialMT_Plain_16);
        display.drawString(0, 16, "C" + String(startDMXChannel) + ": " + String(valD0));
        display.drawString(0, 33, "C" + String(startDMXChannel + 1) + ": " + String(valD1));
        display.drawString(0, 49, "C" + String(startDMXChannel + 2) + ": " + String(valA0));
        display.drawString(70, 16, "C" + String(startDMXChannel + 3) + ": " + String(valD2));
        display.drawString(70, 33, "C" + String(startDMXChannel + 4) + ": " + String(valD3));
        display.drawString(70, 49, "C" + String(startDMXChannel + 5) + ": " + String(valA1));
        eStop = false;
#if debug
        Serial.print(": ok - ");
#endif
      }
      else
      {
        eStop = true;
        panic();
        sinSenal();
#if debug
        Serial.print(": fail - ");
#endif
      }

      valD0 = DMX::Read(startDMXChannel);
      valD1 = DMX::Read(startDMXChannel + 1);
      valA0 = DMX::Read(startDMXChannel + 2);
      valD2 = DMX::Read(startDMXChannel + 3);
      valD3 = DMX::Read(startDMXChannel + 4);
      valA1 = DMX::Read(startDMXChannel + 5);

#if debug
      Serial.print(valD0);
      Serial.print(" - ");
      Serial.print(valD1);
      Serial.print(" - ");
      Serial.print(valA0);
      Serial.print(" - ");
      Serial.print(valD2);
      Serial.print(" - ");
      Serial.print(valD3);
      Serial.print(" - ");
      Serial.println(valA1);
#endif
    }
  }
  /////////////////////////
  //        MQTT         //
  ////////////////////////
  if (modo == HIGH) {
    if (!cliente.connected()) {
      reconnect();
    }
    display.clear();
    display.setTextAlignment(TEXT_ALIGN_LEFT);
    display.setFont(ArialMT_Plain_16);
    display.drawString(0, 16, "C" + String(startDMXChannel) + ": " + String(valD0));
    display.drawString(0, 33, "C" + String(startDMXChannel + 1) + ": " + String(valD1));
    display.drawString(0, 49, "C" + String(startDMXChannel + 2) + ": " + String(valA0));
    display.drawString(70, 16, "C" + String(startDMXChannel + 3) + ": " + String(valD2));
    display.drawString(70, 33, "C" + String(startDMXChannel + 4) + ": " + String(valD3));
    display.drawString(70, 49, "C" + String(startDMXChannel + 5) + ": " + String(valA1));

    cliente.loop();
  }
  if ((valD0 == 255 && valD1 == 255) || eStop || (valD2 == 255 && valD3 == 255)) {
    panic();
  }
  else {
    //Salida digital 0
    if (valD0 == 255) {
      digitalWrite(dOut0, HIGH);
    }
    else {
      digitalWrite(dOut0, LOW);
    }
    //Salida digital 1
    if (valD1 == 255) {
      digitalWrite(dOut1, HIGH);
    }
    else {
      digitalWrite(dOut1, LOW);
    }
    //Salida digital 2
    if (valD2 == 255) {
      digitalWrite(dOut2, HIGH);
    }
    else {
      digitalWrite(dOut2, LOW);
    }
    //Salida digital 3
    if (valD3 == 255) {
      digitalWrite(dOut3, HIGH);
    }
    else {
      digitalWrite(dOut3, LOW);
    }
  }
  if (!eStop) {
    dacWrite(DAC0, valA0);
    dacWrite(DAC1, valA1);
  }
  else {
    dacWrite(DAC0, 0);
    dacWrite(DAC1, 0);
  }

  if (showChannel && millis() - chShowTimer < 5000) {
    display.clear();
    display.setFont(ArialMT_Plain_24);
    display.setTextAlignment(TEXT_ALIGN_CENTER);
    display.drawString(64, 32, "CH " + String(startDMXChannel));
  }
  else {
    showChannel = false;
    if (saveChannel) {
      EEPROM.write(0, startDMXChannel);
      EEPROM.commit();
      saveChannel = false;
      display.clear();
      display.drawString(64, 32, "SAVED");
      display.display();
      delay(1000);
    }
  }
  display.display();
}

void panic() {
  digitalWrite(dOut0, LOW);
  digitalWrite(dOut1, LOW);
  digitalWrite(dOut2, LOW);
  digitalWrite(dOut3, LOW);
}

void sinSenal() {
  // Draw a pixel at given position
  if (render && millis() - lastShow > 1000) {
    for (int i = 0; i < 21; i++) {
      display.setPixel(54 + i, 22 + i);
      display.setPixel(74 - i, 22 + i);
    }
    lastShow = millis();
  }
  else {
    display.clear();
  }
  render = !render;
  display.setTextAlignment(TEXT_ALIGN_CENTER);
  display.setFont(ArialMT_Plain_16);
  display.drawString(64, 43, "SIN SEÑAL");
}

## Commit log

2021-11-04 Modified the schematic to include the following features: * Added 2 additional digital outputs * Replaced relay output with BPJ optocoupler * Replaced PWM output with 2 DAC outputs passing through an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
2022-04-01 updated gerber files
2025-02-01 Added KiCAD and Eagle PCB files. Updated KiCAD main board to V3
    [DMXtoMotionPCB-v2.brd, DMXtoMotionPCB-v2.sch, DMXtoMotionPCB_V3.kicad_pcb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]
2025-02-04 Slight modifications on KiCAD V3 files. Generated fabrication files
    [DMXtoMotionPCB_V3-B_Cu.gbr, DMXtoMotionPCB_V3-B_Mask.gbr, DMXtoMotionPCB_V3-B_Silkscreen.gbr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]
2025-02-05 Changes of through hole diameters in KiCAD V3 and BOM
    [DMXtoMotionPCB_V3-B_Cu.gbr, DMXtoMotionPCB_V3-B_Mask.gbr, DMXtoMotionPCB_V3-B_Silkscreen.gbr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]
2025-02-05 KiCAD files
    [Sheet1.kicad_sch]
2025-02-05 lista de materiales semiactualizada
    [DMXtoMotionPCB_V3.csv]
2025-02-05 double checked through holes and part names. Completed BOM
    [DMXtoMotionPCB_V3-B_Cu.gbr, DMXtoMotionPCB_V3-B_Mask.gbr, DMXtoMotionPCB_V3-B_Silkscreen.gbr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]
2025-02-05 trace adjustments
    [DMXtoMotionPCB_V3-B_Cu.gbr, DMXtoMotionPCB_V3-B_Mask.gbr, DMXtoMotionPCB_V3-B_Silkscreen.gbr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]
2025-02-06 Actualización de componentes obsoletos
    [DMXtoMotionPCB_V3.csv, DMXtoMotionPCB_V3.kicad_pcb]
2025-02-06 Actualización de lista de componentes
    [DMXtoMotionPCB_V3.csv]
